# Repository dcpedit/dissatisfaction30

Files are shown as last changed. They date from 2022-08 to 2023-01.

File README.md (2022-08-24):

# Dissatisfaction30 Macropad

dissat-2

Here you will find all the source files I used for my build.

[Keyboard Layout Editor (KLE)](http://www.keyboard-layout-editor.com/#/gists/a50e7cce1739c047275b94c15fb516cc)

# Image Gallery
https://imgur.com/a/5sZTefW

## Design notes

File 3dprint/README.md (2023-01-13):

# 3D printed case

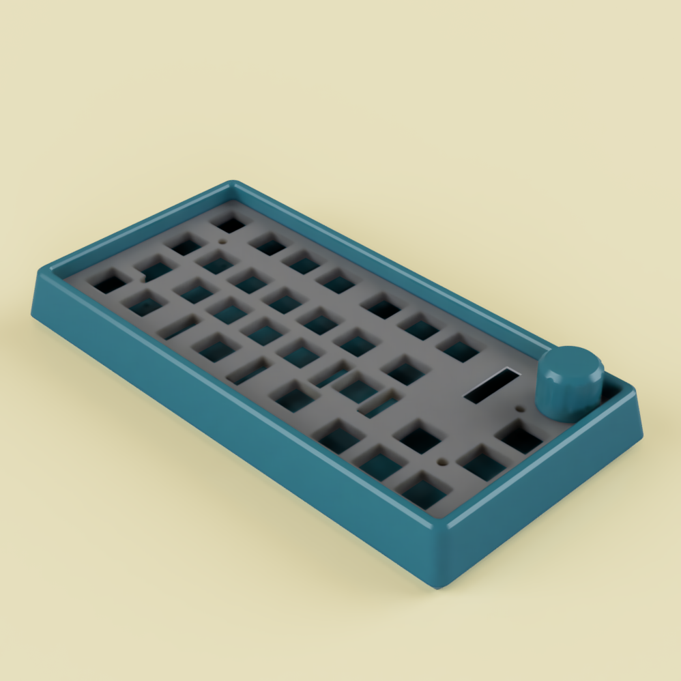
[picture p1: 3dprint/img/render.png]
render


A simple tray-mount case for the Dissatisfaction30.
Consists of a 5mm thick plate, which is secured to the case using the 4 screw holes of the PCB, mounted on standoffs.
If you want to use this case, you should use normal header pins to solder the EliteC/Pro micro to the PCB.

### Hardware required
- 5mm M2 standoffs (4x)
- M2 screws, about 5mm (4x)
- M2 nuts (4x)

### Printing
Print the plate and the knob upside down, no supports are required. You will have to punch open the 4 screw holes in the plate.

### Building
- Push the 4 nuts into the holes at the bottom of the case. Screw the standoffs into the holes from the top and tighten them.
- You can put some 2-3mm foam at the bottom of the case to act as sound dampener if you want.
- Sandwich the plate between the PCB and the switches, and drop it into the case.
- Use the 4 screws to secure the plate to the standoffs.

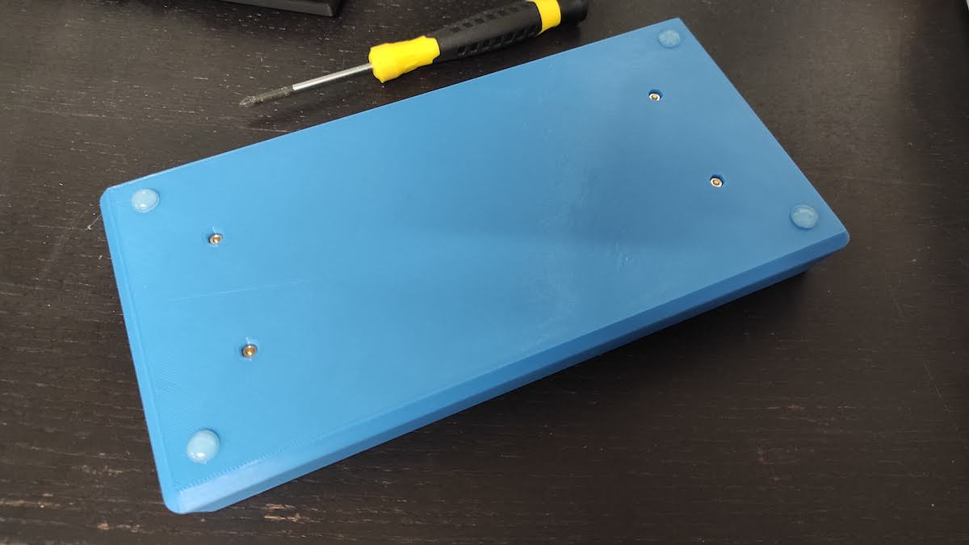
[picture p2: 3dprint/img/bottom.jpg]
bottom


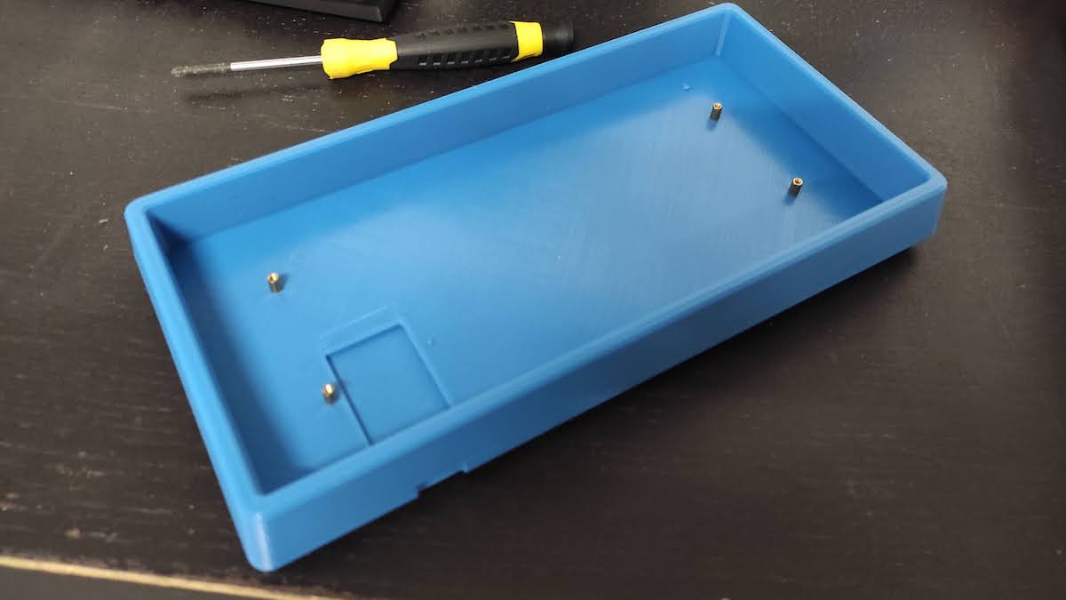
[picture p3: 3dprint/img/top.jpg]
top


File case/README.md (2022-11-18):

# Dissatisfaction30 Stacked Acrylic Case (prototype)



This is a tray mount case that still needs a lot of design improvements.  The goal was to hide the case screws by using adhesive to secure to top 2 layers.  You will need the following hardware

## Case
| Position | Size | Quantity | Notes |
| --- | ---- | --- | ----- |
| Upper | M2x8mm standoff | 3 |
| Lower | M2x13mm standoffs | 3 |
| Top | M2x8mm screws | 6 |
| Bottom | M2x6mm screws | 6 |
| | 3mm acrylic | 9 layers |
| | Double sided adhesive | 1 | [Link](https://smile.amazon.com/gp/product/B00CCGK31G/)

## PCB Mount
| Position | Size | Quantity |
| --- | ---- | --- |
| | M2x6mm standoff | 4 |
| Top | M2x4mm screw | 4 |
| Bottom | M2x3mm screw | 4 |

## Foam & Plate
| Layer Name | Size | Quantity | Notes |
| --- | ---- | --- | ----- |
|  a) Plate foam | 1.5mm EVA | 1 | [Link](https://www.aliexpress.com/item/3256804208838525.html?spm=a2g0o.order_list.0.0.61751802IXEFAW) |
|  a) Plate foam | 2mm EVA | 1 |
|  b) Bottom foam | 1.5mm EVA | 1 |
|  c) Plate holes | 1.5mm acrylic | 1 |

## Guide
Use `plate-mount.ai` and cut the 9 layers of acrylic needed for the case (labled `#1` - `#9`).  You will also need to cut 3 layers of EVA foam (see table above for layer name and thickness).  Screw layers `#3` - `#9` together (see case table above for screw/standoff positions).  Do not secure the first two layers yet since they will be held on top by the double-sided adhesive.



Place the 1.5mm bottom foam on the bottom of the case.  Attach the M2x6mm standoffs to the bottom of the PCB using the M2x4mm screws.  Place the PCB with standoffs attached over the bottom foam, and secure the PCB to the case with M2x4mm from the underside of the case. It may seem like the bottom mount holes are too big since the entire spacer fits through, but this was intentional in order reduce space under the PCB.  The intent was for the bottom foam to be just thick enough to keep the screws flush against the case bottom.



Place the 2mm and 1.5mm plate foam on top of the PCB, and then the switch plate on top of the 2 layers of foam, making sure the switch holes are lined up.  Push all the switches into the switch plate.  You can put together the PCB + plate foam + plate + switches first, and then place the whole assembly inside the case.



Cut strips of double-sided adhesive so that they fit around the edges of the layer `#3` and secure layer `#2` on top, making sure it's centered.  Cut more strips of double-sided adhesive and place them around the edges of layer `#2`.  Finally secure the top layer `#1` on top while making sure it's centered.



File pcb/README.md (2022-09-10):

# Dissatisfaction30 PCB

Dissatisfaction30 - Imgur

To get the PCB manufactured, upload `dissat-pcb.zip` to [JLCPCB](https://jlcpcb.com), select your desired PCB color while keeping all the other default options, and place your order (minimum 5).  If you made tweaks to the PCB in KiCad, follow [this tutorial](https://support.jlcpcb.com/article/194-how-to-generate-gerber-and-drill-files-in-kicad-6) to generate new Gerber files

## Requied Components
| Name | Qty | Notes |
| --- | --- | ----- |
| Elite-C controller | 1 | Soldered directly onto PCB
| SSD1306 128x32 OLED | 1 |
| EC11 rotary encoder | 1 |
| Key switches | 30  |
| 3u stabalizer | 1 |
| 2u stabalizer | 1 |
| OLED header (1x4) | 1 | [Link](https://www.mouser.com/ProductDetail/517-929850-01-04-RA)
| Kailh hot swap socket  | 30  | [Link](https://www.aliexpress.com/item/2255800865526224.html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)
| BAV70 SMD diode | 16  | [Link](https://www.digikey.com/en/products/detail/onsemi/BAV70LT3G/1475508)

You will need to sand the OLED header down so that the plastic is about 7mm in height (not including the pins).  Also remove any plastic spacers on the OLED pins, and make sure the pins insert fully into the now shorter header.  If it doesn't sit flush with the OLED PCB, cut the OLED pins a bit shorter until it does.



It is also possible to replace the Elite-C with a nice!nano for wireless support or a Pro-Micro since the bottom 5 pins are not used.  But the included case design expects the controler to be soldered directly onto the PCB, so using a controller that requires low-profile sockets (I suggest Mill-Max 315-43-112-41-003000) will also require a change to the case to allow for the extra height.  Try cutting out a space below the controller on layer `#8` (similar to layer `#7`)





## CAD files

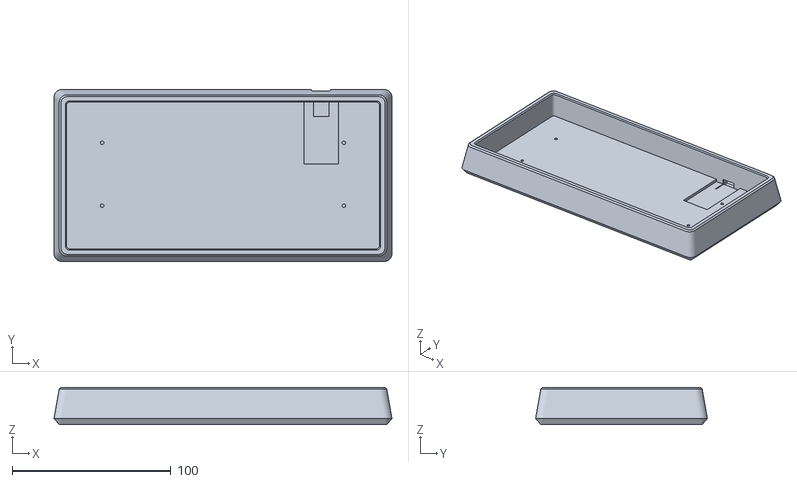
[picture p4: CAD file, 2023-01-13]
3dprint/stl/case.stl
213.1 x 108.3 x 23.6

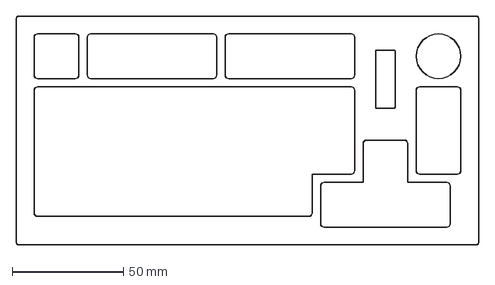
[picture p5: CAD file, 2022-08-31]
case/plate-mount.dxf
207.5 x 102.7 mm

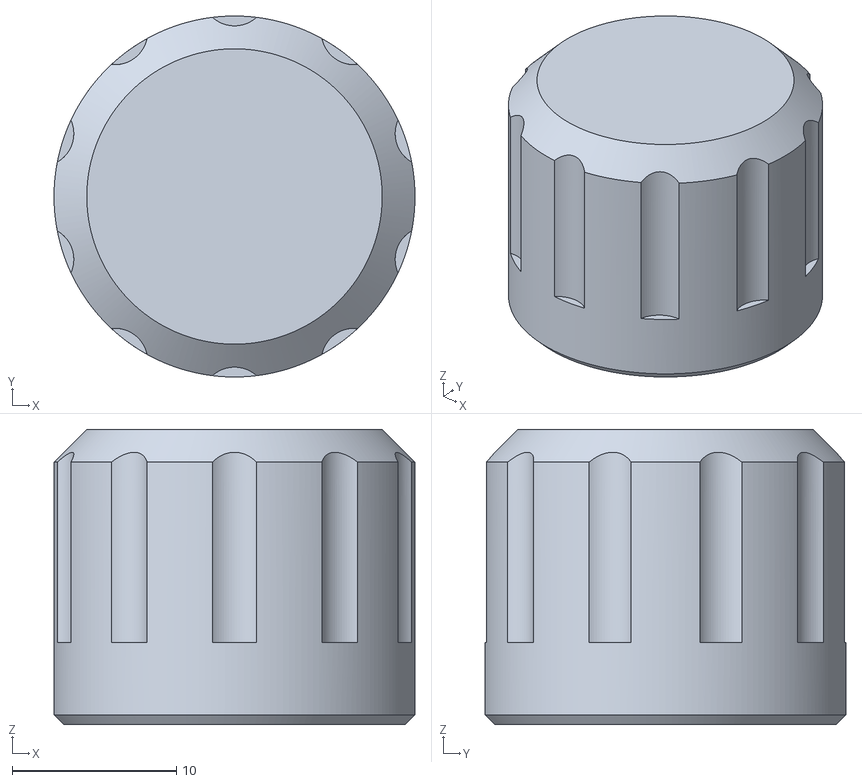
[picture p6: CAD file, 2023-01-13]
3dprint/stl/knob.stl
22.0 x 22.0 x 18.0

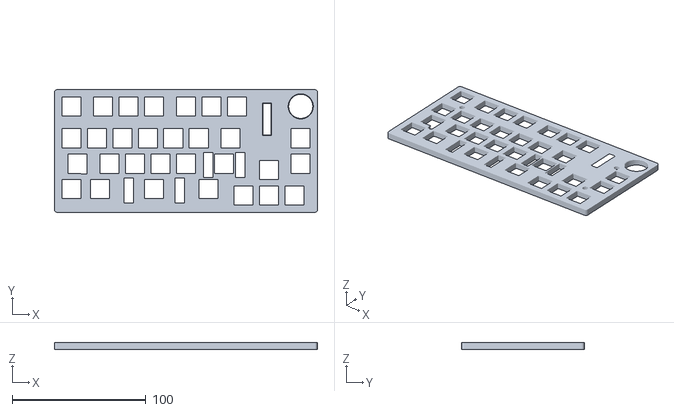
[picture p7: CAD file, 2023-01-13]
3dprint/stl/plate.stl
196.5 x 91.7 x 5.00

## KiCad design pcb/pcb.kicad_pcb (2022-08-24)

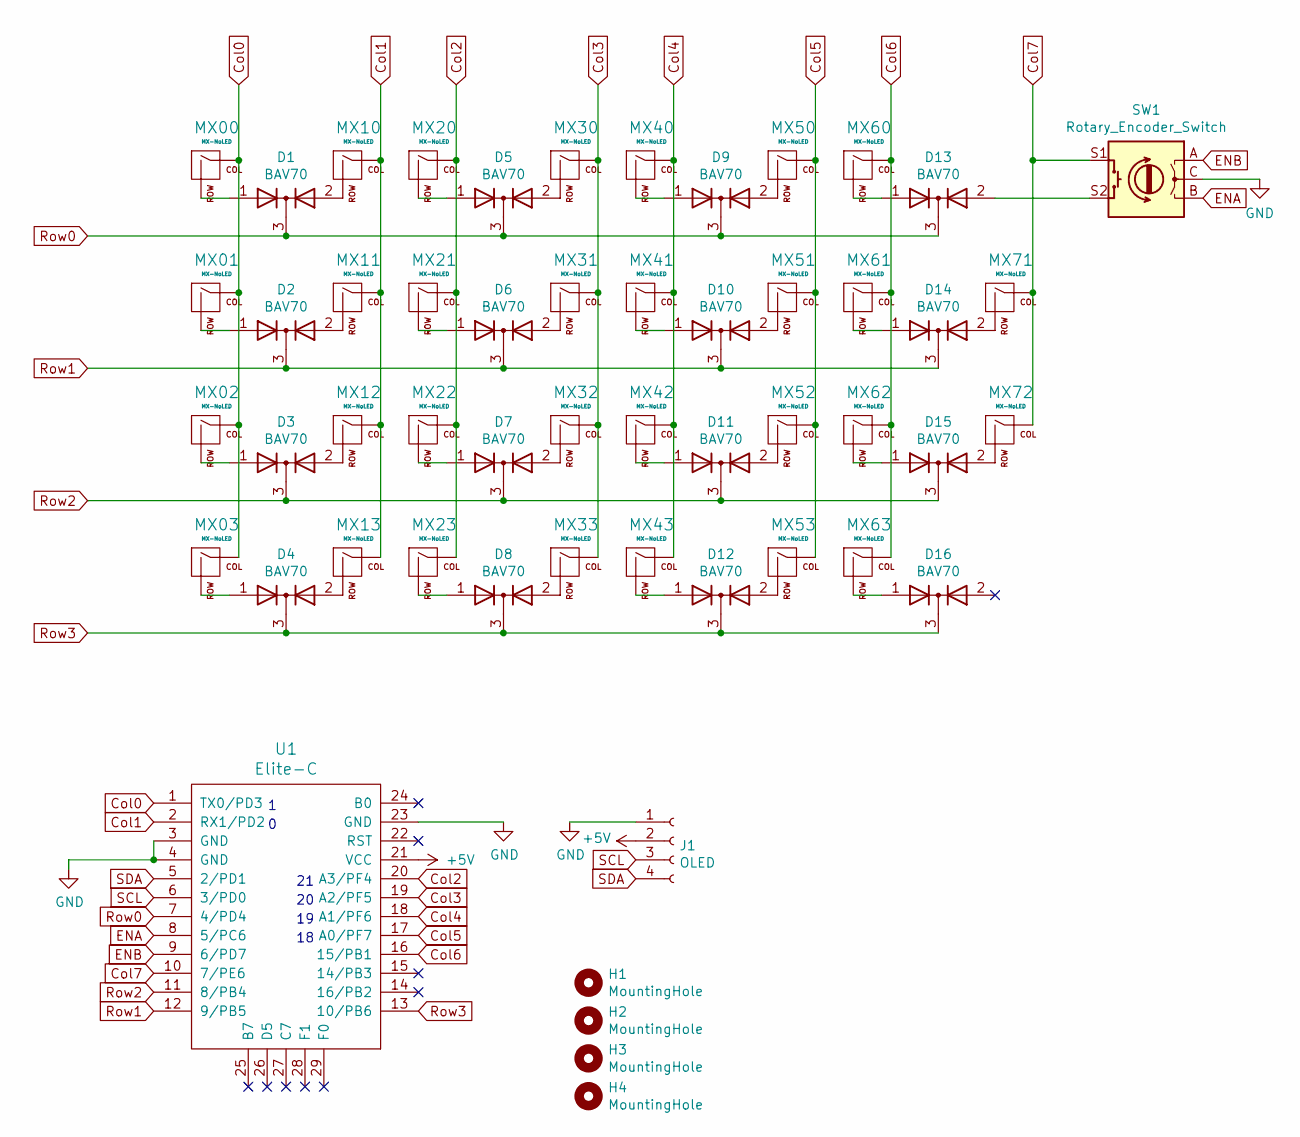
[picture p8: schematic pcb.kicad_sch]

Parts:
D1, D2, D3, D4, D5, D6, D7, D8, D9, D10, D11, D12, D13, D14, D15, D16: BAV70; SOT-23_Handsoldering
H1, H2, H3, H4: MountingHole; MountingHole_2.2mm_M2_Pad
J1: OLED; SSD1306_OLED
MX00, MX10, MX11, MX12, MX13, MX20, MX21, MX22, MX23, MX30, MX31, MX32, MX33, MX40, MX41, MX42, MX43, MX50, MX51, MX52, MX53, MX60, MX61, MX62, MX63, MX71, MX72: MX-NoLED; MXOnly-1U-Hotswap
MX01: MX-NoLED; MXOnly-1.5U-Hotswap
MX02: MX-NoLED; MXOnly-1.75U-Hotswap
MX03: MX-NoLED; MXOnly-2.25U-Hotswap
SW1: Rotary_Encoder_Switch; RotaryEncoder_Alps_EC11E-Switch_Vertical_H20mm
U1: Elite-C

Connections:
+5V: J1.2, U1.21 (VCC)
Col0: MX00.1 (COL), MX01.1 (COL), MX02.1 (COL), MX03.1 (COL), U1.1 (TX0/PD3)
Col1: MX10.1 (COL), MX11.1 (COL), MX12.1 (COL), MX13.1 (COL), U1.2 (RX1/PD2)
Col2: MX20.1 (COL), MX21.1 (COL), MX22.1 (COL), MX23.1 (COL), U1.20 (A3/PF4)
Col3: MX30.1 (COL), MX31.1 (COL), MX32.1 (COL), MX33.1 (COL), U1.19 (A2/PF5)
Col4: MX40.1 (COL), MX41.1 (COL), MX42.1 (COL), MX43.1 (COL), U1.18 (A1/PF6)
Col5: MX50.1 (COL), MX51.1 (COL), MX52.1 (COL), MX53.1 (COL), U1.17 (A0/PF7)
Col6: MX60.1 (COL), MX61.1 (COL), MX62.1 (COL), MX63.1 (COL), U1.16 (15/PB1)
Col7: MX71.1 (COL), MX72.1 (COL), SW1.S1, U1.10 (7/PE6)
ENA: SW1.B, U1.8 (5/PC6)
ENB: SW1.A, U1.9 (6/PD7)
GND: J1.1, SW1.C, U1.3 (GND), U1.4 (GND), U1.23 (GND)
unnamed: D1.1 (A), MX00.2 (ROW)
unnamed: D1.2 (A), MX10.2 (ROW)
unnamed: D2.1 (A), MX01.2 (ROW)
unnamed: D2.2 (A), MX11.2 (ROW)
unnamed: D3.1 (A), MX02.2 (ROW)
unnamed: D3.2 (A), MX12.2 (ROW)
unnamed: D4.1 (A), MX03.2 (ROW)
unnamed: D4.2 (A), MX13.2 (ROW)
unnamed: D5.1 (A), MX20.2 (ROW)
unnamed: D5.2 (A), MX30.2 (ROW)
unnamed: D6.1 (A), MX21.2 (ROW)
unnamed: D6.2 (A), MX31.2 (ROW)
unnamed: D7.1 (A), MX22.2 (ROW)
unnamed: D7.2 (A), MX32.2 (ROW)
unnamed: D8.1 (A), MX23.2 (ROW)
unnamed: D8.2 (A), MX33.2 (ROW)
unnamed: D9.1 (A), MX40.2 (ROW)
unnamed: D9.2 (A), MX50.2 (ROW)
unnamed: D10.1 (A), MX41.2 (ROW)
unnamed: D10.2 (A), MX51.2 (ROW)
unnamed: D11.1 (A), MX42.2 (ROW)
unnamed: D11.2 (A), MX52.2 (ROW)
unnamed: D12.1 (A), MX43.2 (ROW)
unnamed: D12.2 (A), MX53.2 (ROW)
unnamed: D13.1 (A), MX60.2 (ROW)
unnamed: D13.2 (A), SW1.S2
unnamed: D14.1 (A), MX61.2 (ROW)
unnamed: D14.2 (A), MX71.2 (ROW)
unnamed: D15.1 (A), MX62.2 (ROW)
unnamed: D15.2 (A), MX72.2 (ROW)
unnamed: D16.1 (A), MX63.2 (ROW)
Row0: D1.3 (K), D5.3 (K), D9.3 (K), D13.3 (K), U1.7 (4/PD4)
Row1: D2.3 (K), D6.3 (K), D10.3 (K), D14.3 (K), U1.12 (9/PB5)
Row2: D3.3 (K), D7.3 (K), D11.3 (K), D15.3 (K), U1.11 (8/PB4)
Row3: D4.3 (K), D8.3 (K), D12.3 (K), D16.3 (K), U1.13 (10/PB6)
SCL: J1.3, U1.6 (3/PD0)
SDA: J1.4, U1.5 (2/PD1)

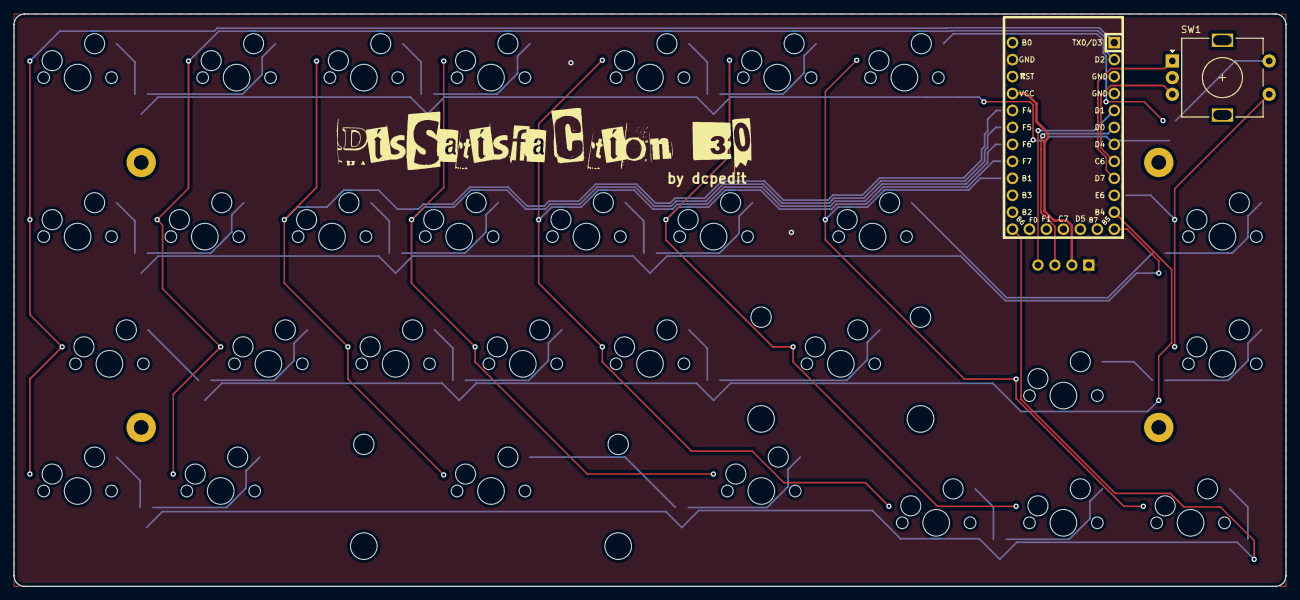
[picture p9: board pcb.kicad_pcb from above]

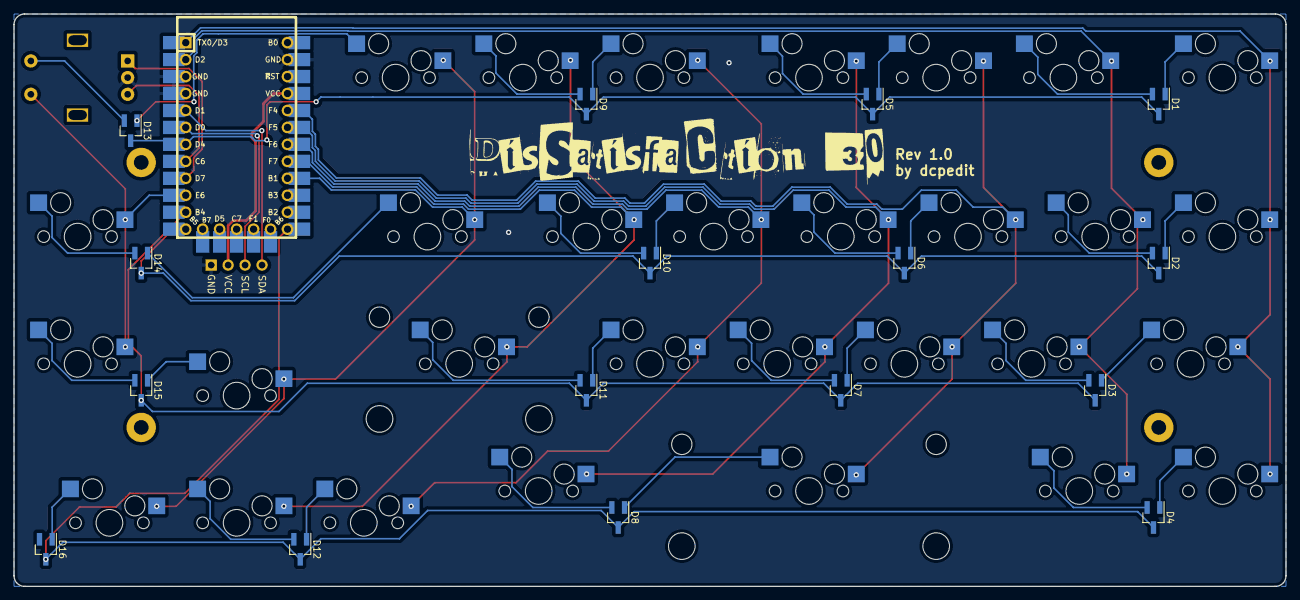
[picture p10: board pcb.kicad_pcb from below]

Board: 2 copper layers, 190.5 x 85.7 mm, 53 parts (17 on the bottom side), 49 nets.

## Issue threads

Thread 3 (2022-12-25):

Which microcontroller should be used?

t2ac32, 2022-12-25:
Sorry I’m barely new in all this keyboard hobby.

I was wondering which microcontroller is shown being used in the photos and recommended to use for the PCB file.

Thanks in advanced

DrBomer, 2023-04-04:
pro micro with 32U4

dcpedit, 2023-11-03:
Any controller with a pro-micro compatible footprint will work, but my case was designed for an Elite-C since it can be soldered directly to the PCB.  An Elite-Pi could theoretically work as well, but I haven't tried it

Closed 2023-11-03.

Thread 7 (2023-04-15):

No Layers for Acrylic Case

noteggroll, 2023-04-15:
under the case folder, there is missing case layer files. The only layer available is top piece.

qqxxsc, 2023-11-02:
I also found this problem and wonder if it is possible to use top-level files for clipping

dcpedit, 2023-11-03:
I just tried opening the DXF file in Inkscape and I'm able to see all the layers (#1 - 9).

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

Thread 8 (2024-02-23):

STEP file formats

aguccislide, 2024-02-23:
Hey, big fan of the project!

Are there any plans on releasing STEP files of the printed case? Would like to CNC mill a case myself :)
Thanks!

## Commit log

2022-08-30 Readme and cleanup for case
2022-08-31 PCB readme
2022-08-31 Add dxf file
    [plate-mount.dxf]
2022-10-16 Fix screw sizes
2022-10-18 Fix standoff size
2022-11-18 Update README.md
    Correct standoff size
2023-01-13 add 3d printed case files
    [case.stl, knob.stl, plate.stl]
